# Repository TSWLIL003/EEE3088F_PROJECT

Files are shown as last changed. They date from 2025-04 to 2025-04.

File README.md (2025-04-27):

**Project Overview**

This repository contains the design files and documentation for the power subsystem of the EEE3088F 2025 Micro-mouse project. The power module is responsible for providing regulated power to all components of the maze-solving robot while adhering to strict budget constraints.

**Key Features**

Dual-voltage power supply (3.3V @ 300mA and 5V @ 1.5A)

Battery charging system with two charging modes (200mA and 600mA)

USB-C power input with 9V output capability

Motor control for 4 DC motors (2x 200mA, 2x 500mA)

I2C-based battery monitoring via INA219

Low-power switch (<30μA in OFF state)

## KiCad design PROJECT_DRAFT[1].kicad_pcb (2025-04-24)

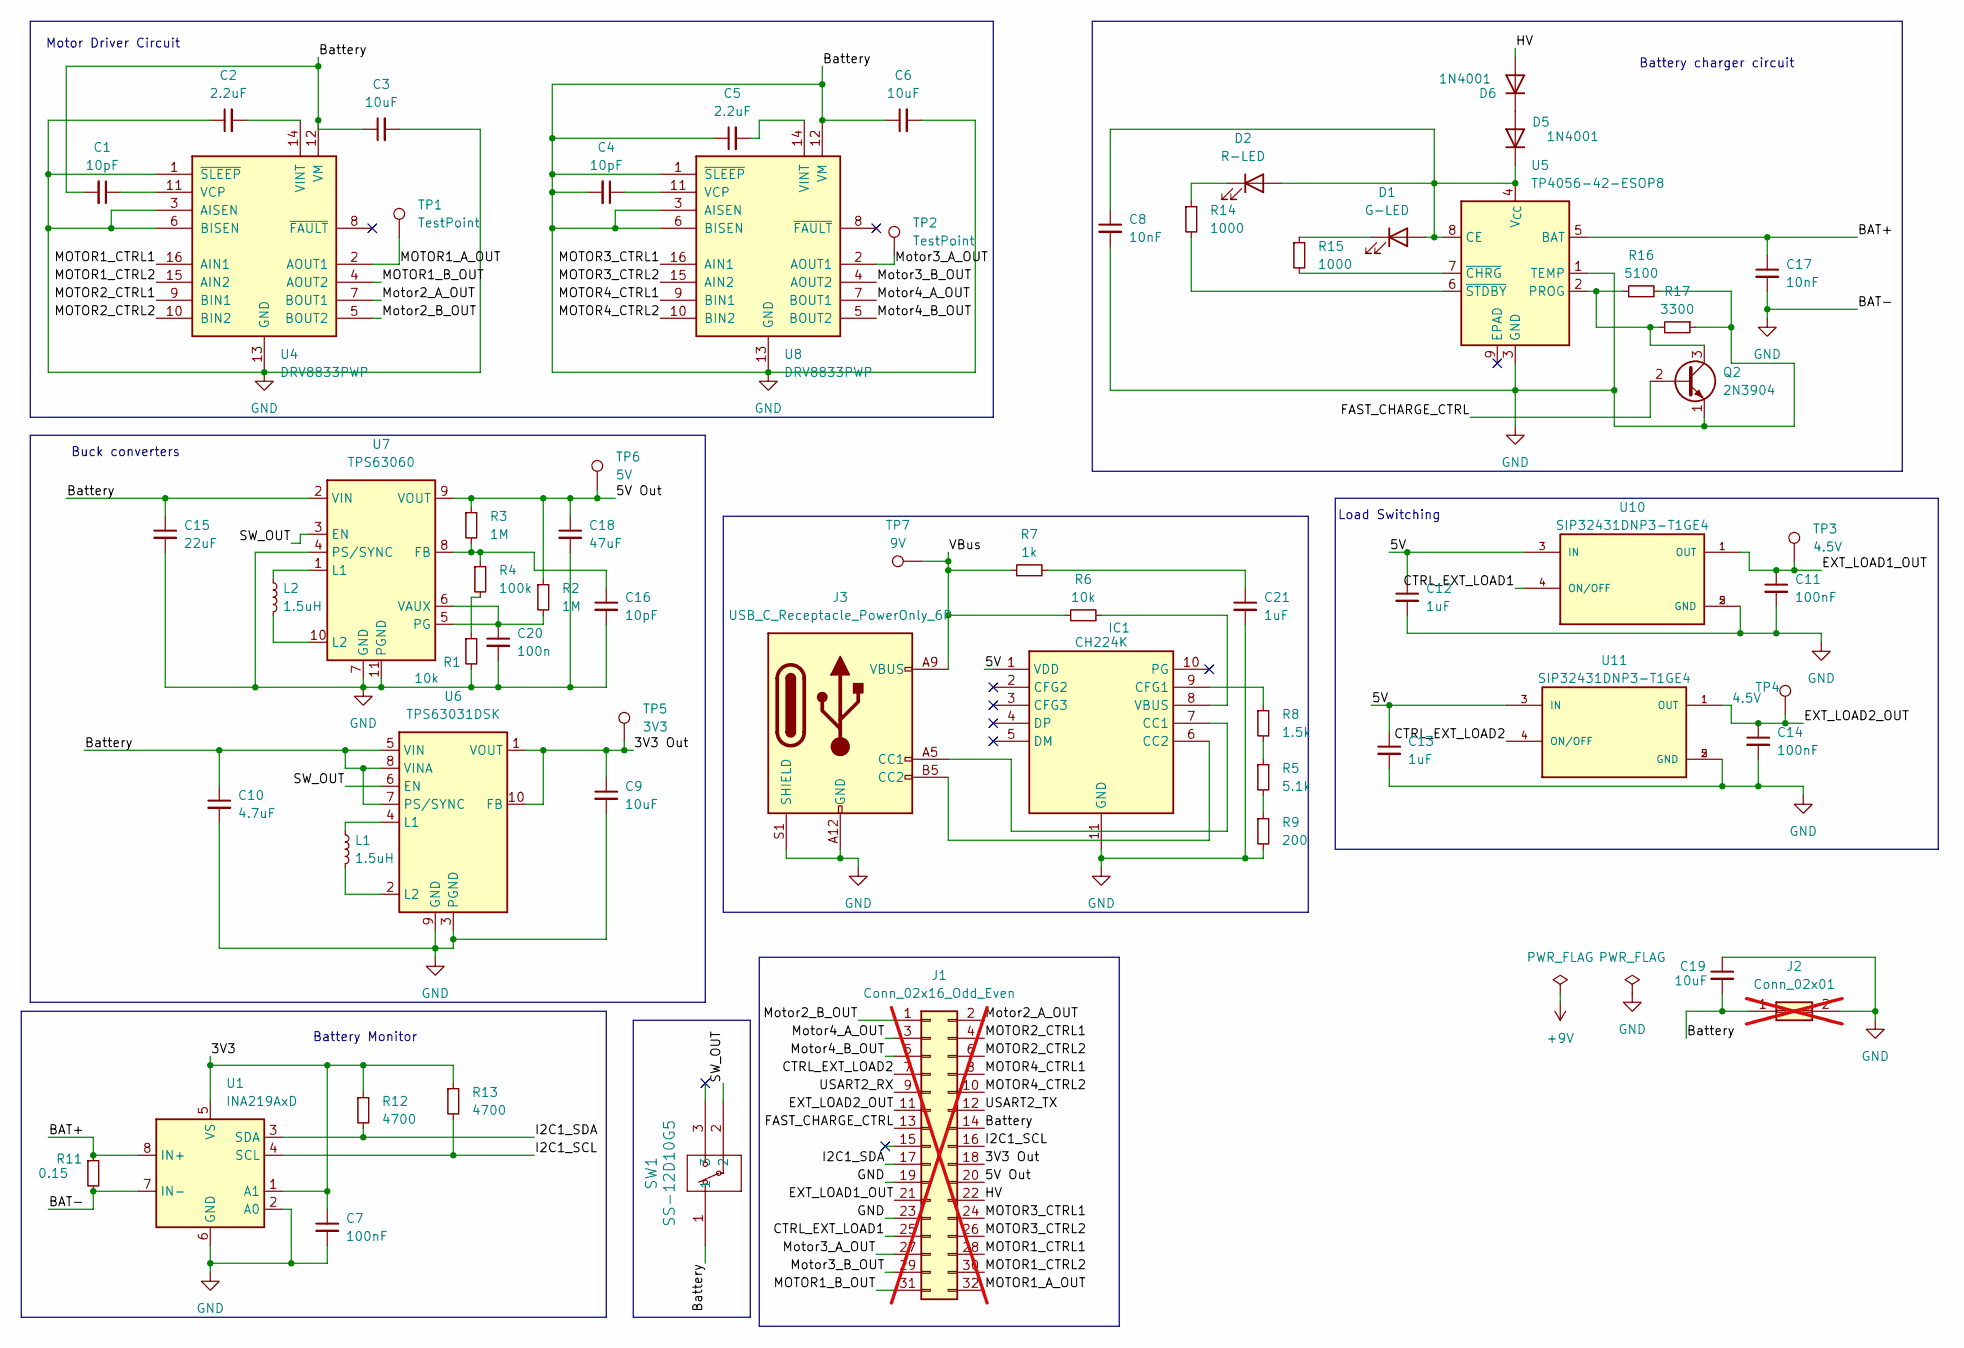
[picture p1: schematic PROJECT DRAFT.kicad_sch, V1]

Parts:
C1, C4, C16: 10pF; C_0603_1608Metric_Pad1.08x0.95mm_HandSolder; LCSC C1634
C2: 2.2uF; C_0402_1005Metric_Pad0.74x0.62mm_HandSolder; LCSC C12530
C3, C6, C9: 10uF; CP_EIA-3216-18_Kemet-A_Pad1.58x1.35mm_HandSolder; LCSC C7171
C5: 2.2uF; C_0402_1005Metric_Pad0.74x0.62mm_HandSolder
C7, C11, C14: 100nF; C_0402_1005Metric_Pad0.74x0.62mm_HandSolder; LCSC C1525
C8, C17: 10nF; C_0805_2012Metric_Pad1.18x1.45mm_HandSolder; LCSC C1710
C10: 4.7uF; C_0805_2012Metric_Pad1.18x1.45mm_HandSolder; LCSC C1779
C12, C13: 1uF; C_1206_3216Metric_Pad1.33x1.80mm_HandSolder; LCSC C1848
C15: 22uF; C_1206_3216Metric_Pad1.33x1.80mm_HandSolder; LCSC C12891
C18: 47uF; C_0805_2012Metric_Pad1.18x1.45mm_HandSolder; LCSC C16780
C19: 10uF; CP_EIA-3216-10_Kemet-I_Pad1.58x1.35mm_HandSolder; LCSC C149670
C20: 100n; C_0402_1005Metric_Pad0.74x0.62mm_HandSolder; LCSC C1525
C21: 1uF; C_1206_3216Metric_Pad1.33x1.80mm_HandSolder
D1: G-LED; LED_0603_1608Metric_Pad1.05x0.95mm_HandSolder; LCSC C2286
D2: R-LED; LED_0603_1608Metric_Pad1.05x0.95mm_HandSolder; LCSC C2286
D5, D6: 1N4001; D_DO-41_SOD81_P10.16mm_Horizontal
IC1: CH224K; SOP100P600X180-11N; Manufacturer_Part_Number CH224K; LCSC C970725
J1: Conn_02x16_Odd_Even; PinHeader_2x16_P2.54mm_Vertical; not fitted
J2: Conn_02x01; JST_PH_B2B-PH-K_1x02_P2.00mm_Vertical; not fitted
J3: USB_C_Receptacle_PowerOnly_6P; USB_C_Receptacle_GCT_USB4125-xx-x-0190_6P_TopMnt_Horizontal; LCSC C168701
L1, L2: 1.5uH; L_0402_1005Metric_Pad0.77x0.64mm_HandSolder; LCSC C84470
Q2: 2N3904; SOT-23; LCSC C18536
R1: 10k; R_0805_2012Metric_Pad1.20x1.40mm_HandSolder; LCSC C17414
R2, R3: 1M; R_0805_2012Metric_Pad1.20x1.40mm_HandSolder; LCSC C17514
R4: 100k; R_0805_2012Metric_Pad1.20x1.40mm_HandSolder; LCSC C17900
R5: 5.1k; R_0201_0603Metric_Pad0.64x0.40mm_HandSolder; LCSC C23186
R6: 10k; R_0805_2012Metric_Pad1.20x1.40mm_HandSolder
R7: 1k; R_1206_3216Metric_Pad1.30x1.75mm_HandSolder; LCSC C4410
R8: 1.5k; R_0805_2012Metric_Pad1.20x1.40mm_HandSolder; LCSC C4310
R9: 200; R_0603_1608Metric_Pad0.98x0.95mm_HandSolder; LCSC C8218
R11: 0.15; R_1206_3216Metric_Pad1.30x1.75mm_HandSolder; LCSC C149670
R12, R13: 4700; C_0805_2012Metric_Pad1.18x1.45mm_HandSolder; LCSC C17673
R14, R15: 1000; R_1206_3216Metric_Pad1.30x1.75mm_HandSolder; LCSC C4410
R16: 5100; R_0603_1608Metric_Pad0.98x0.95mm_HandSolder; LCSC C23186
R17: 3300; R_0603_1608Metric_Pad0.98x0.95mm_HandSolder; LCSC C22978
SW1: SS-12D10G5; SS-12D10G5_XKB; LCSC C2884744
TP1, TP2: TestPoint; TestPoint_Pad_2.5x2.5mm
TP3, TP4: 4.5V; TestPoint_Pad_2.5x2.5mm
TP5: 3V3; TestPoint_Pad_2.5x2.5mm
TP6: 5V; TestPoint_Pad_2.5x2.5mm
TP7: 9V; TestPoint_Pad_2.5x2.5mm
U1: INA219AxD; SOIC-8_3.9x4.9mm_P1.27mm; LCSC C87469
U4: DRV8833PWP; TSSOP-16-1EP_4.4x5mm_P0.65mm_EP3x3mm_ThermalVias; LCSC C50506
U5: TP4056-42-ESOP8; SOIC-8-1EP_3.9x4.9mm_P1.27mm_EP2.41x3.3mm_ThermalVias
U6: TPS63031DSK; WSON-10-1EP_2.5x2.5mm_P0.5mm_EP1.2x2mm; LCSC C15516
U7: TPS63060; Texas_S-PWSON-N10; LCSC C48567
U8: DRV8833PWP; TSSOP-16-1EP_4.4x5mm_P0.65mm_EP3x3mm; LCSC C50506
U10, U11: SIP32431DNP3-T1GE4; SON50P120X160X60-5N; PARTREV Rev F; LCSC C727398

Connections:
/3V3: C7.1, R12.1, R13.1, U1.1 (A1), U1.5 (VS)
/3V3 Out: C9.1, J1.18, TP5.1, U6.1 (VOUT), U6.10 (FB)
/5V: C12.1, C13.1, IC1.1 (VDD), U10.3 (IN), U11.3 (IN)
/5V Out: C18.1, J1.20, R2.1, R3.1, TP6.1, U7.9 (VOUT)
/BAT+: C17.1, R11.1, U1.8 (IN+), U5.5 (BAT)
/CTRL_EXT_LOAD1: U10.4 (ON/OFF)
/CTRL_EXT_LOAD1: J1.25
/CTRL_EXT_LOAD2: J1.7, U11.4 (ON/OFF)
/EXT_LOAD1_OUT: C11.1, J1.21, TP3.1, U10.1 (OUT)
/EXT_LOAD2_OUT: C14.1, J1.11, TP4.1, U11.1 (OUT)
/FAST_CHARGE_CTRL: J1.13, Q2.2 (B)
/HV: D6.2 (A), J1.22
/I2C1_SCL: R13.2, U1.4 (SCL)
/I2C1_SCL: J1.16
/I2C1_SDA: R12.2, U1.3 (SDA)
/I2C1_SDA: J1.17
/MOTOR1_A_OUT: J1.32, TP1.1, U4.2 (AOUT1)
/MOTOR1_B_OUT: J1.31, U4.4 (AOUT2)
/MOTOR1_CTRL1: J1.28, U4.16 (AIN1)
/MOTOR1_CTRL2: J1.30, U4.15 (AIN2)
/MOTOR2_CTRL1: J1.4, U4.9 (BIN1)
/MOTOR2_CTRL2: J1.6, U4.10 (BIN2)
/MOTOR3_CTRL1: J1.24, U8.16 (AIN1)
/MOTOR3_CTRL2: J1.26, U8.15 (AIN2)
/MOTOR4_CTRL1: J1.8, U8.9 (BIN1)
/MOTOR4_CTRL2: J1.10, U8.10 (BIN2)
/Motor2_A_OUT: J1.2, U4.7 (BOUT1)
/Motor2_B_OUT: J1.1, U4.5 (BOUT2)
/Motor3_A_OUT: J1.27, TP2.1, U8.2 (AOUT1)
/Motor3_B_OUT: J1.29, U8.4 (AOUT2)
/Motor4_A_OUT: J1.3, U8.7 (BOUT1)
/Motor4_B_OUT: J1.5, U8.5 (BOUT2)
/SW_OUT: SW1.2, U6.6 (EN), U7.3 (EN)
/USART2_RX: J1.9
/USART2_TX: J1.12
/VBus: J3.A9 (VBUS), J3.B9 (VBUS), R6.1, R7.1, TP7.1
GND: C1.2, C2.1, C3.1, C3.2, C4.2, C5.1, C6.1, C6.2, C7.2, C8.2, C9.2, C10.1, C10.2, C11.2, C12.2, C13.2, C14.2, C15.1, C15.2, C16.2, C17.2, C18.2, C19.1, C19.2, C20.2, C21.2, IC1.11 (GND), J1.14, J1.19, J1.23, J2.1, J2.2, J3.A12 (GND), J3.B12 (GND), J3.S1 (SHIELD), Q2.1 (E), R1.2, R9.2, R11.2, R16.2, R17.1, SW1.1, U1.2 (A0), U1.6 (GND), U1.7 (IN-), U4.1 (~SLEEP), U4.3 (AISEN), U4.6 (BISEN), U4.12 (VM), U4.13 (GND), U4.17 (GND), U5.1 (TEMP), U5.3 (GND), U6.3 (PGND), U6.5 (VIN), U6.7 (PS/SYNC), U6.8 (VINA), U6.9 (GND), U6.11 (PGND), U7.2 (VIN), U7.4 (PS/SYNC), U7.7 (GND), U7.11 (PGND), U8.1 (~SLEEP), U8.3 (AISEN), U8.6 (BISEN), U8.12 (VM), U8.13 (GND), U8.17 (GND), U10.2 (GND), U10.5 (GND), U11.2 (GND), U11.5 (GND)
unnamed: C21.1, R7.2
unnamed: C8.1, D1.2 (A), D2.2 (A), D5.1 (K), U5.4 (V_{CC}), U5.8 (CE)
unnamed: D1.1 (K), R15.1
unnamed: D2.1 (K), R14.1
unnamed: D5.2 (A), D6.1 (K)
unnamed: IC1.7 (CC1), J3.A5 (CC1)
unnamed: IC1.6 (CC2), J3.B5 (CC2)
unnamed: IC1.9 (CFG1), R8.1
unnamed: IC1.8 (VBUS), R6.2
unnamed: Q2.3 (C), R16.1, R17.2, U5.2 (PROG)
unnamed: R1.1, R4.2
unnamed: R5.1, R8.2
unnamed: R5.2, R9.1
unnamed: C1.1, U4.11 (VCP)
unnamed: C2.2, U4.14 (VINT)
unnamed: R15.2, U5.7 (~CHRG)
unnamed: R14.2, U5.6 (~STDBY)
unnamed: L1.1, U6.4 (L1)
unnamed: L1.2, U6.2 (L2)
unnamed: C16.1, R3.2, R4.1, U7.8 (FB)
unnamed: L2.1, U7.1 (L1)
unnamed: L2.2, U7.10 (L2)
unnamed: C20.1, R2.2, U7.5 (PG), U7.6 (VAUX)
unnamed: C4.1, U8.11 (VCP)
unnamed: C5.2, U8.14 (VINT)

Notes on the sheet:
Load Switching
Buck converters
Motor Driver Circuit
Battery charger circuit
Battery Monitor

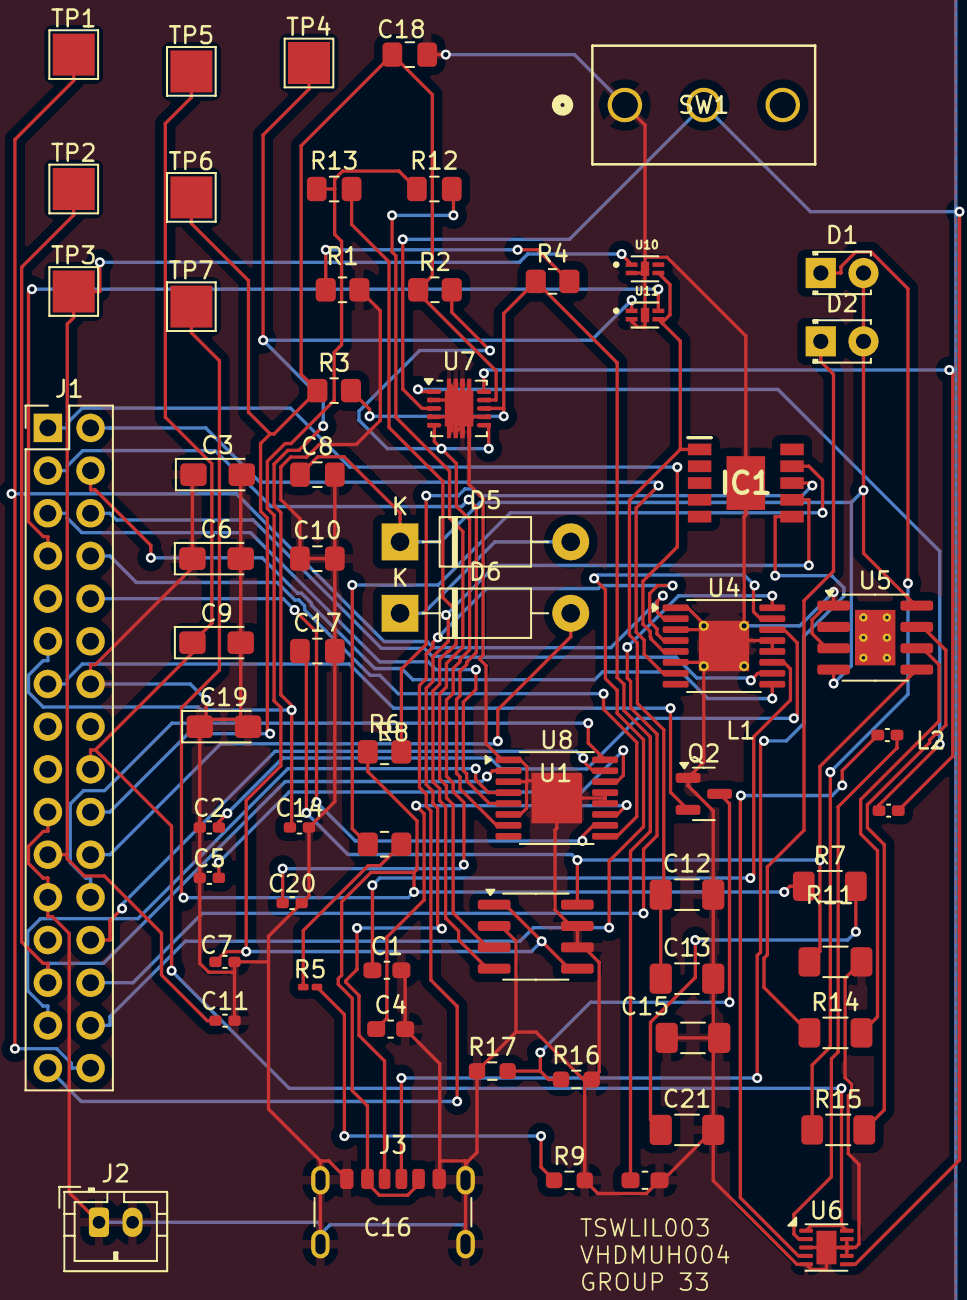
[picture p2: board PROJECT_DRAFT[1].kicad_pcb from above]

Board: 2 copper layers, 64 parts (0 on the bottom side), 56 nets.

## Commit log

2025-04-24 Update PROJECT DRAFT.kicad_sch
    Added H-bridge circuit for motors
    [PROJECT DRAFT.kicad_sch]
2025-04-24 Update PROJECT_DRAFT[1].kicad_pcb
    Add comments
    [PROJECT_DRAFT[1].kicad_pcb]
